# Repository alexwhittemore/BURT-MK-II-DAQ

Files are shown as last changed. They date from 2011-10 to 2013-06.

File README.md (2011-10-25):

BURT Mk-II DAQ
==============

Boston University Rocket Team's Mk-II Data Acquisition and Control System.

Background
----------
The Boston University Rocket Team is currently focused on advancing hybrid rocket motor design and research. The Mk-II is a static (never leaves the ground) test bed for experimentation with various design parameters like chamber and oxidizer injector geometries.

### Sensors
The DAQ side consists of multiple sensors: pressure transducers, load cells, and thermocouples.

There are two pressure transducers, each rated at 500PSI full scale. The Oxidizer Line Transducer measures the pressure on the nitrous oxide feed line right before the injector. This should match the vapor pressure of N2O, roughly 750PSI dependent on temperature. The Combustion Chamber Transducer measures the pressure INSIDE the combustion chamber, directly after the injector. For Mk-II, the design chamber pressure is 500PSI

There are also two load cells. The Thrust Load Cell is an S-Beam, 500lbs full scale load cell. Design thrust is 75lbs. The Oxidizer Tank Cell is a canteliver 50lbs cell. This measures the weight of the Nitrous Oxide tank used to feed the motor, where change in mass of the tank can be used to calculate mass flow rate of oxidizer.

There are three thermocouples. All are K-type. One NPT-threaded, sealed TC measures oxidizer temperature before the injector. One of two silicone surface adhesive TCs measures the oxidizer tank temperature. The other of these measures the combustion chamber casing temperature. A spike in this temperature indicates a fault with the fuel grain casting and a potentially unsafe conditon that could result in a burn-through of the schedule-80 steel casing.

### Boards
All of these are read by four wheatstone bridge digitizer boards (Bridge Digitizer.sch) and three K-type thermocouple digitizer boards (Thermocouple Digitizer.sch). The outputs of these boards are read via SPI by an mbed microcontroller residing on a main board. This main board also holds a zigbee radio which forwards a UART connection to a host computer for off-site (safe distance) live monitoring of the system, as well as a USB plug for a thumb drive to log the live, real-time acquired data. Additionally, a UART is broken out on a set of .1" spaced headers to connect to a sparkfun graphical LCD for on-site monitoring. Finally, two pins are broken out on a DB-9 connector to serve as software serial to a safe distance physical control interface. This could just as easily be run exclusively via zigbee radio.

### Control
The final job of the system is to control the burn itself. This is handled by two pneumatic valves, switched by 24-volt electric solenoids in turn controlled by the mbed via a quad-half H-bridge chip on the main board. These solenoids are either open or spring-shut, and thus only require two outputs of the quad half Bridge. A third output is used to control a nichrome wire-based pyrotechnic ignitor. The fourth half bridge is implemented but unused.

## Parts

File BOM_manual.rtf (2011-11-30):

1uF tantalum filter board cap DigiKey #399-3678-1-ND
USB A sockets DigiKey #GSB311131HR-ND
Tip29 DigiKey #TIP29CFS-ND
1k 25 turn gain trim pots DigiKey #3296w-102LF-ND
filter clock driver Mouser #863-M74VHC1GT126DT1G
Female Break-away Headers DigiKey #929974E-01-36-ND
Male Break-away Headers DigiKey #929834E-01-36-ND
16 Pin IC Socket Sparkfun
Screw Terminals - 2pos 5MM Sparkfun
Xbee headers Sparkfun
DB9 board-mount plugs Sparkfun

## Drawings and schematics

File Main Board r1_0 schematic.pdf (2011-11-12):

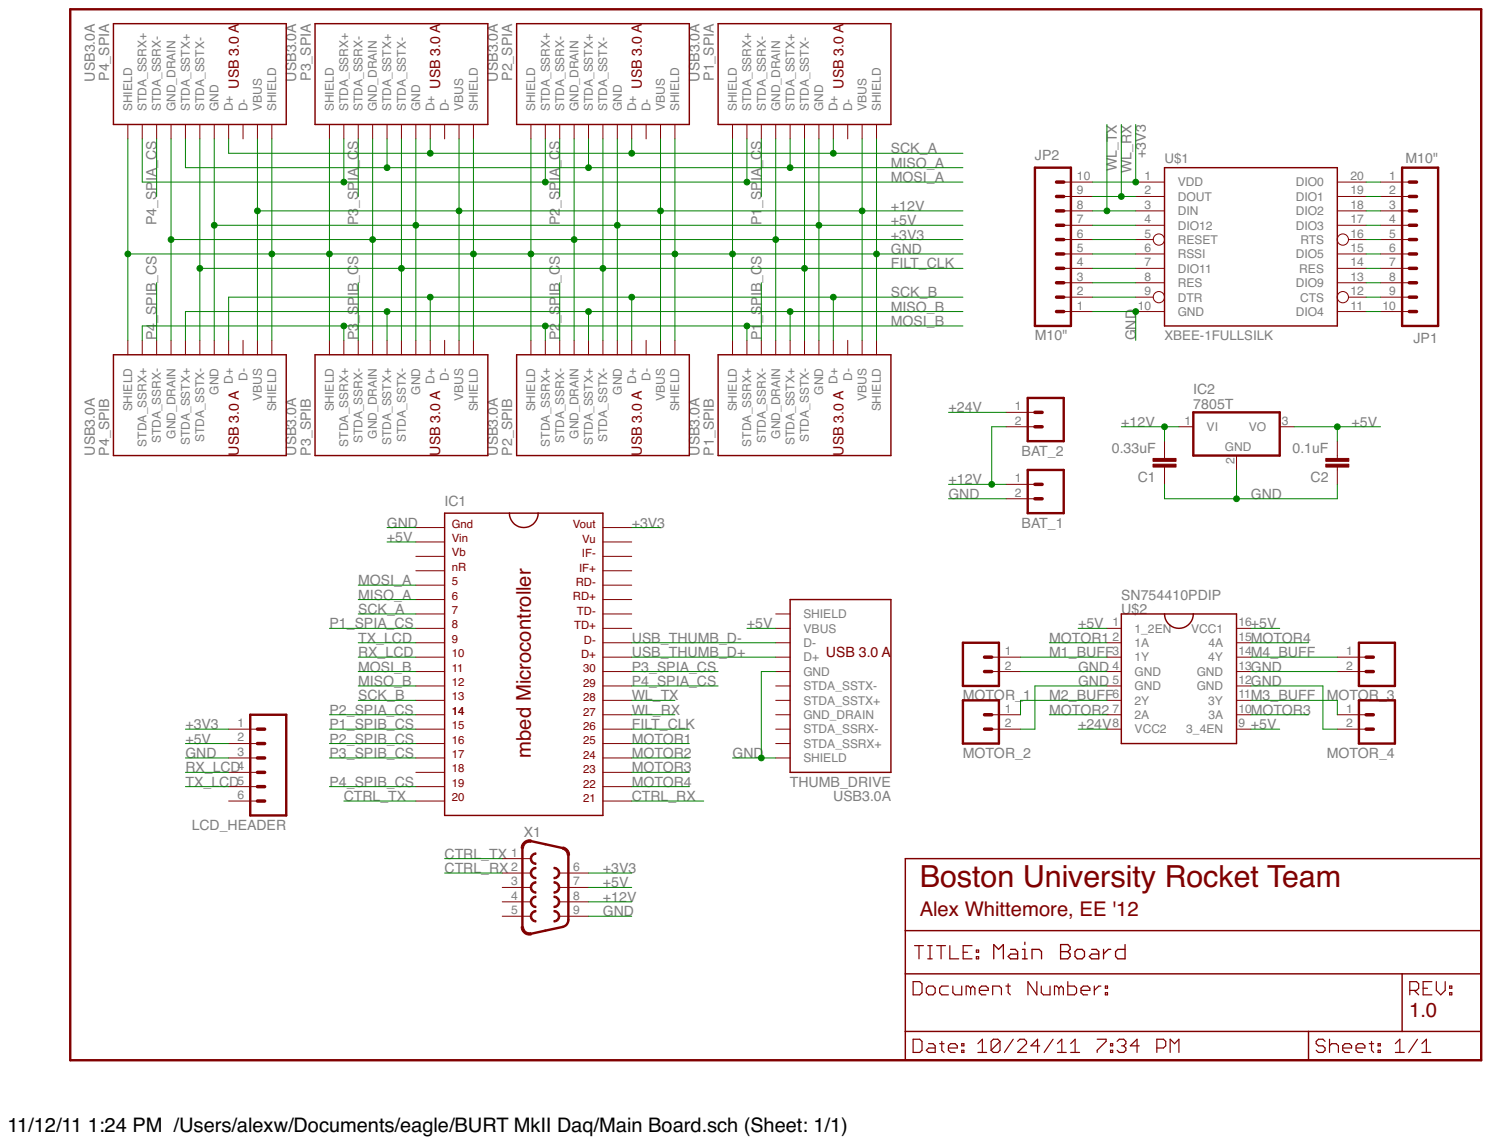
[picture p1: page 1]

Vout Vu

11/12/11 1:24 PM /Users/alexw/Documents/eagle/BURT MkII Daq/Main Board.sch (Sheet: 1/1)

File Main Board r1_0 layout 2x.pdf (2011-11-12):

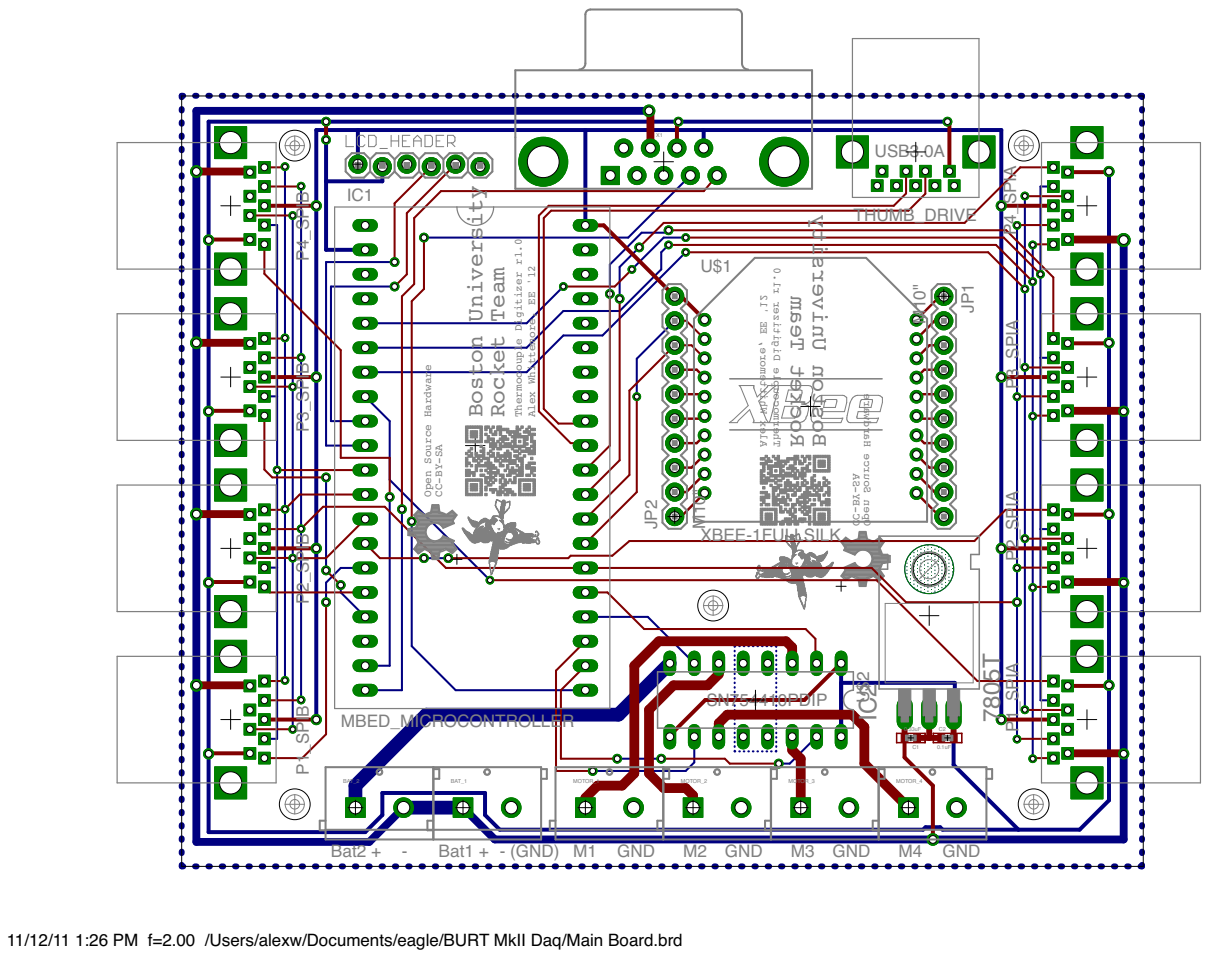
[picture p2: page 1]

11/12/11 1:26 PM f=2.00 /Users/alexw/Documents/eagle/BURT MkII Daq/Main Board.brd

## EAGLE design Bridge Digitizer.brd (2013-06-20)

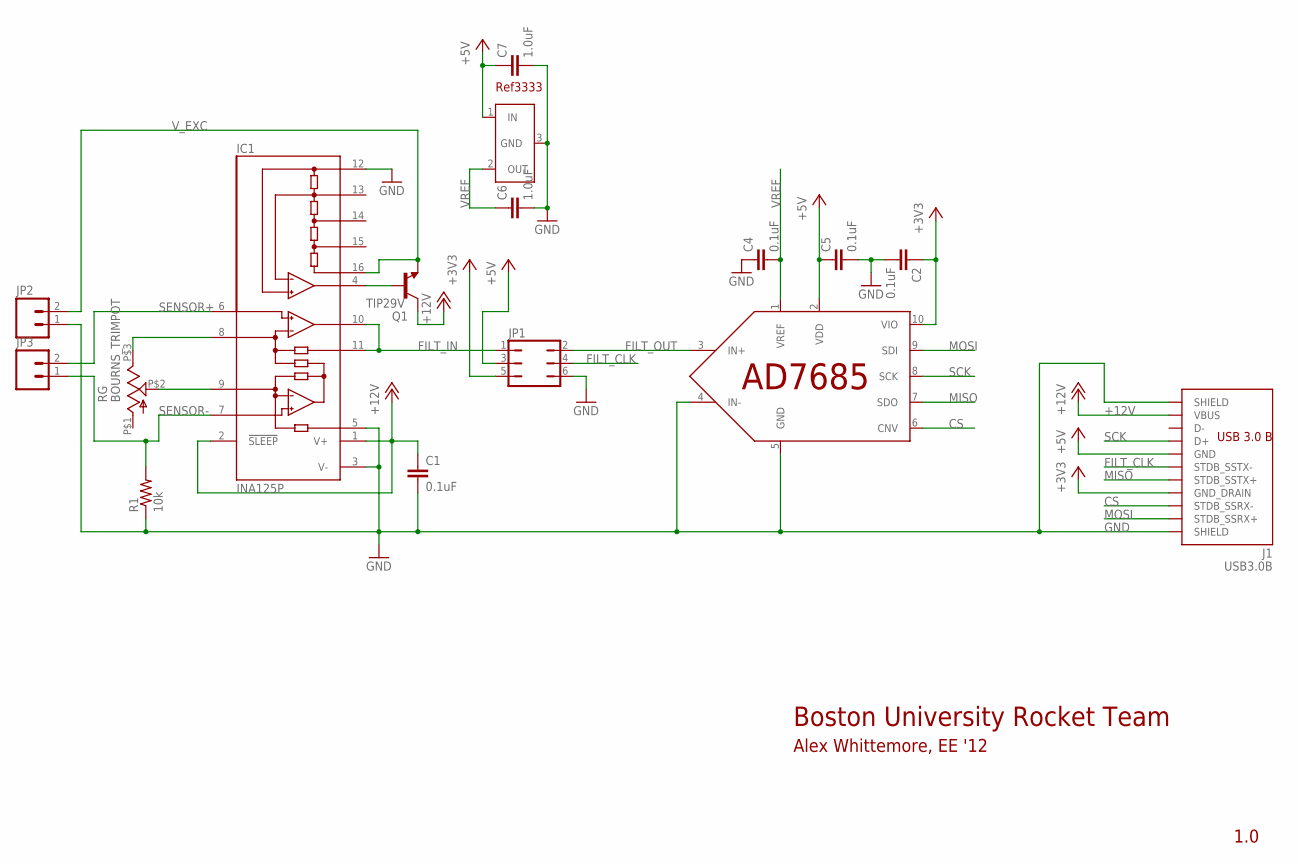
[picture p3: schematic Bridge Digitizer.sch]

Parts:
C1, C2, C4, C5: 0.1uF; 0402-CAP
C6, C7: 1.0uF; 0402-CAP
IC1: INA125P; DIL16
IC3: AD7685; MSOP10
IC4: REF3333; SOT23
J1: USB3.0B; AMPHENOLUSB3.0B
JP1: JP3Q
JP2, JP3: M025MM; SCREWTERMINAL-5MM-2
Q1: TIP29V; TO220V
R1: 10k; 0207/7
RG: BOURNS_TRIMPOT; 3296W

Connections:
+3V3: C2.1, IC3.10 (VIO), J1.7 (GND_DRAIN), JP1.5
+5V: C5.1, C7.1, IC3.2 (VDD), IC4.1 (IN), J1.4 (GND), JP1.3
+12V: C1.1, IC1.1 (V+), IC1.2 (!SLEEP), J1.1 (VBUS), Q1.2 (C)
CS: IC3.6 (CNV), J1.8 (STDB_SSRX-)
FILT_CLK: J1.5 (STDB_SSTX-), JP1.4
FILT_IN: IC1.10 (OUT), IC1.11 (SENSE), JP1.1
FILT_OUT: IC3.3 (IN+), JP1.2
GND: C1.2, C2.2, C4.1, C5.2, C6.2, C7.2, IC1.3 (V-), IC1.5 (REF), IC1.12 (REFCOM), IC3.4 (IN-), IC3.5 (GND), IC4.3 (GND), J1.10@1 (SHIELD), J1.10@2 (SHIELD), JP1.6, JP2.1, R1.1
MISO: IC3.7 (SDO), J1.6 (STDB_SSTX+)
MOSI: IC3.9 (SDI), J1.9 (STDB_SSRX+)
unnamed: IC1.4 (REFOUT), Q1.1 (B)
unnamed: IC1.9 (RG), RG.P$2 (2)
unnamed: IC1.8 (RG), RG.P$3 (3)
SCK: IC3.8 (SCK), J1.3 (D+)
SENSOR+: IC1.6 (+IN), JP3.2
SENSOR-: IC1.7 (-IN), JP3.1, R1.2
VREF: C4.2, C6.1, IC3.1 (VREF), IC4.2 (OUT)
V_EXC: IC1.16 (REF10), JP2.2, Q1.3 (E)

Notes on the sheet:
Boston University Rocket Team
1.0
Alex Whittemore, EE '12

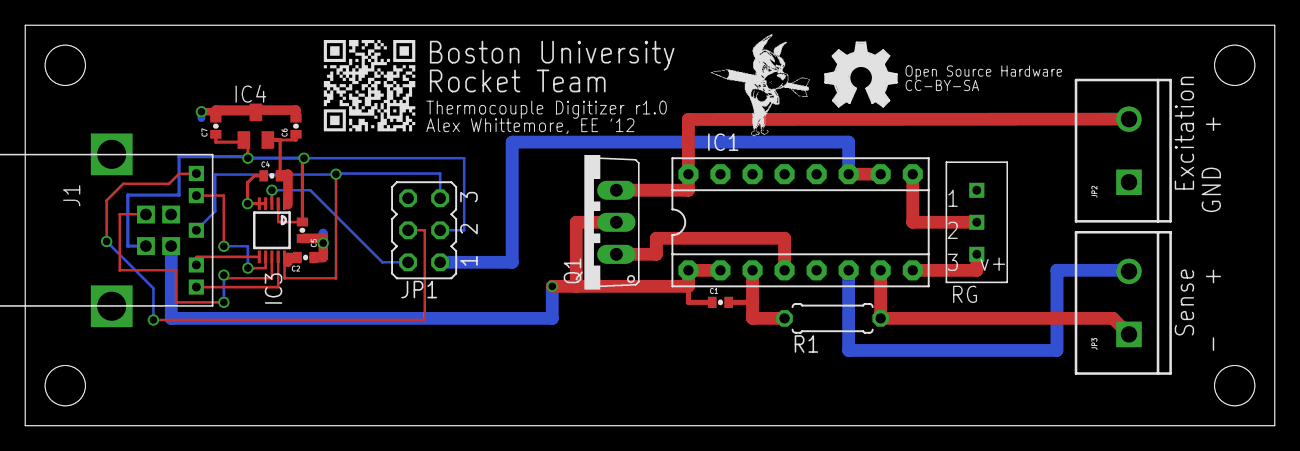
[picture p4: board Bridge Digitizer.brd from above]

Board: 2 copper layers, 99.1 x 31.8 mm, 17 parts (0 on the bottom side), 18 nets.

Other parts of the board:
U$1: OSHW_FILLX200_NOTEXT

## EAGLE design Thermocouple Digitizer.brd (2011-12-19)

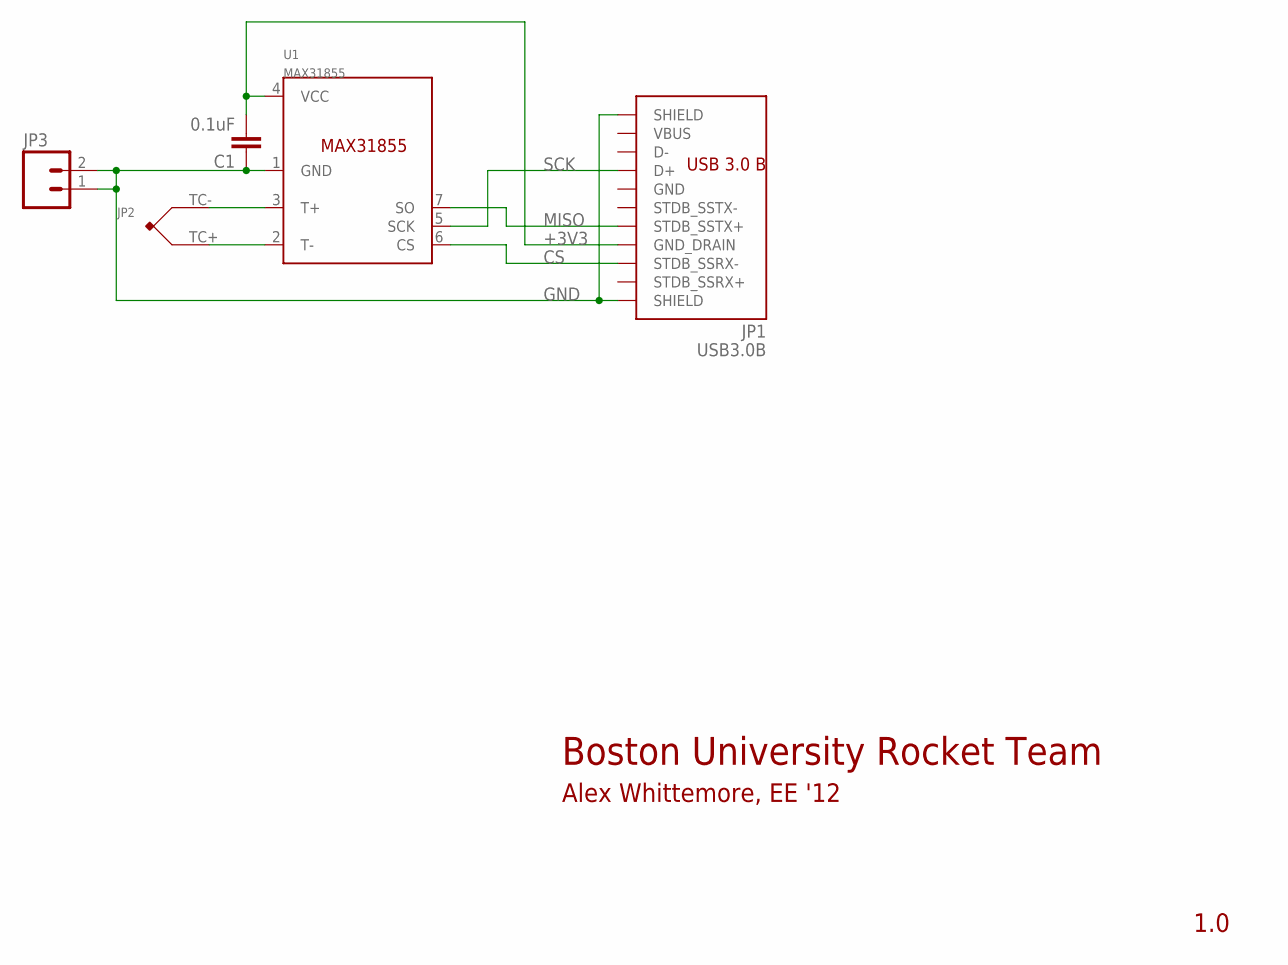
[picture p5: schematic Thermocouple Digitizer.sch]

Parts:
C1: 0.1uF; 0402-CAP
JP1: USB3.0B; AMPHENOLUSB3.0B
JP2: OMEGA_PCC-SMP
JP3: M025MM; SCREWTERMINAL-5MM-2
U1: MAX31855; SOIC8

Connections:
+3V3: C1.2, JP1.7 (GND_DRAIN), U1.4 (VCC)
CS: JP1.8 (STDB_SSRX-), U1.6 (CS)
GND: C1.1, JP1.10@1 (SHIELD), JP1.10@2 (SHIELD), JP3.1, JP3.2, U1.1 (GND)
MISO: JP1.6 (STDB_SSTX+), U1.7 (SO)
unnamed: JP2.TC-, U1.3 (T+)
unnamed: JP2.TC+, U1.2 (T-)
SCK: JP1.3 (D+), U1.5 (SCK)

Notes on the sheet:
Boston University Rocket Team
Alex Whittemore, EE '12
1.0

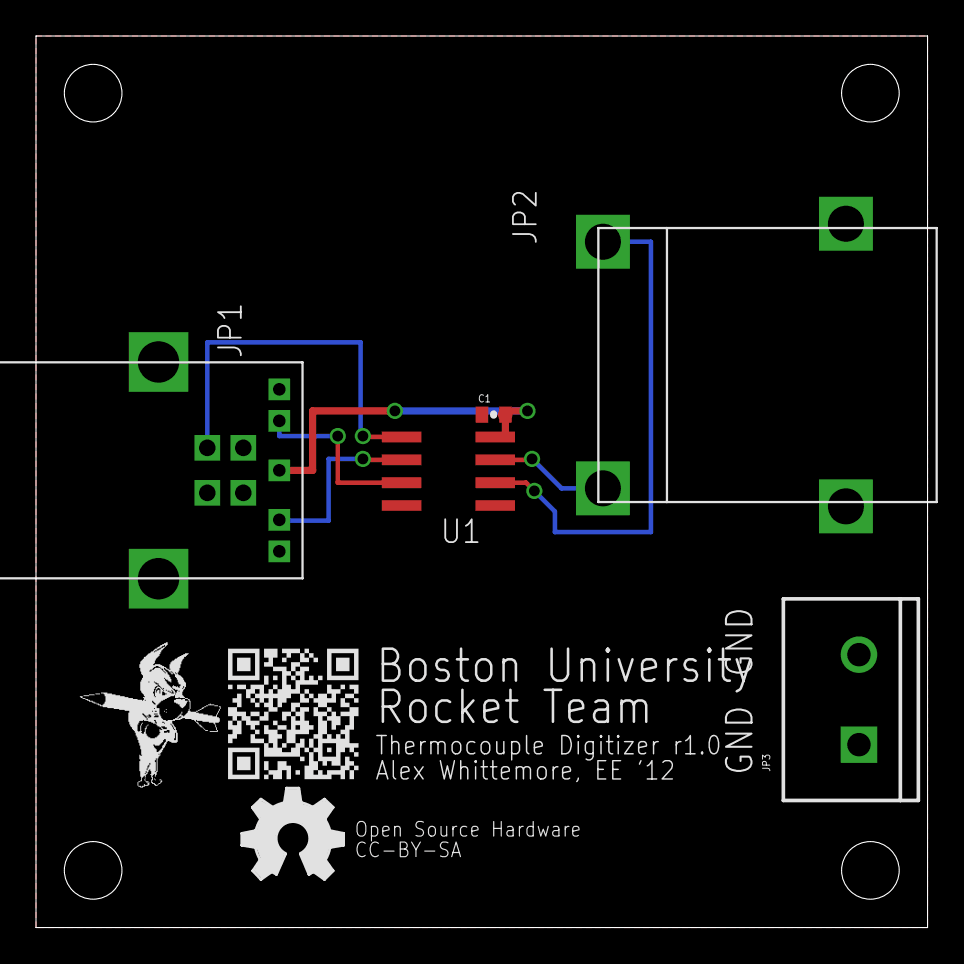
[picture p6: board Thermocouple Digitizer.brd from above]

Board: 2 copper layers, 49.5 x 49.5 mm, 6 parts (0 on the bottom side), 7 nets.

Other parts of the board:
U$1: OSHW_FILLX200_NOTEXT

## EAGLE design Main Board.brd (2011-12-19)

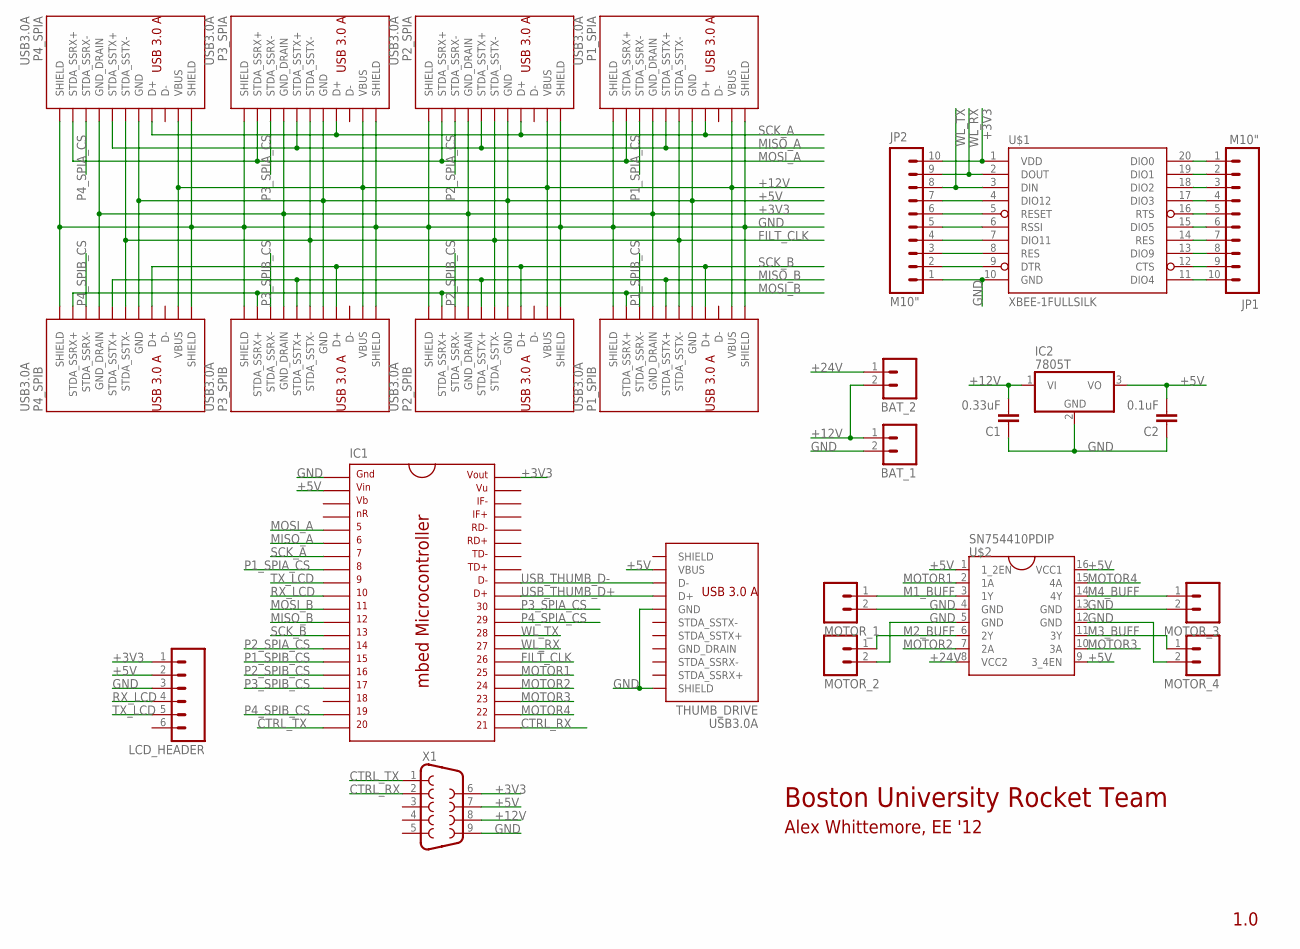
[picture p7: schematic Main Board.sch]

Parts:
BAT_1, BAT_2: M025MM; SCREWTERMINAL-5MM-2
C1: 0.33uF; 0402-CAP
C2: 0.1uF; 0402-CAP
IC1: MBED_MICROCONTROLLER; DIL40_0.9
IC2: 7805T; TO220H
JP1, JP2: M10"; 1X10
LCD_HEADER: M06LOCK; 1X06_LOCK
MOTOR_1, MOTOR_2, MOTOR_3, MOTOR_4: M025MM; SCREWTERMINAL-5MM-2
P1_SPIA, P1_SPIB, P2_SPIA, P2_SPIB, P3_SPIA, P3_SPIB, P4_SPIA, P4_SPIB: USB3.0A; AMPHENOLUSB3.0A
THUMB_DRIVE: USB3.0A; AMPHENOLUSB3.0A
U$1: XBEE-1FULLSILK; XBEE
U$2: SN754410PDIP; DIL16
X1: DB9MALE; DB9_MALE

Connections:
+3V3: IC1.40, JP2.10, LCD_HEADER.1, P1_SPIA.7 (GND_DRAIN), P1_SPIB.7 (GND_DRAIN), P2_SPIA.7 (GND_DRAIN), P2_SPIB.7 (GND_DRAIN), P3_SPIA.7 (GND_DRAIN), P3_SPIB.7 (GND_DRAIN), P4_SPIA.7 (GND_DRAIN), P4_SPIB.7 (GND_DRAIN), U$1.1 (VDD), X1.6
+5V: C2.2, IC1.2, IC2.3 (VO), LCD_HEADER.2, P1_SPIA.4 (GND), P1_SPIB.4 (GND), P2_SPIA.4 (GND), P2_SPIB.4 (GND), P3_SPIA.4 (GND), P3_SPIB.4 (GND), P4_SPIA.4 (GND), P4_SPIB.4 (GND), THUMB_DRIVE.1 (VBUS), U$2.1 (1_2EN), U$2.9 (3_4EN), U$2.16 (VCC1), X1.7
+12V: BAT_1.1, BAT_2.2, C1.2, IC2.1 (VI), P1_SPIA.1 (VBUS), P1_SPIB.1 (VBUS), P2_SPIA.1 (VBUS), P2_SPIB.1 (VBUS), P3_SPIA.1 (VBUS), P3_SPIB.1 (VBUS), P4_SPIA.1 (VBUS), P4_SPIB.1 (VBUS), X1.8
+24V: BAT_2.1, U$2.8 (VCC2)
CTRL_RX: IC1.21, X1.2
CTRL_TX: IC1.20, X1.1
FILT_CLK: IC1.26, P1_SPIA.8 (STDA_SSTX-), P1_SPIB.8 (STDA_SSTX-), P2_SPIA.8 (STDA_SSTX-), P2_SPIB.8 (STDA_SSTX-), P3_SPIA.8 (STDA_SSTX-), P3_SPIB.8 (STDA_SSTX-), P4_SPIA.8 (STDA_SSTX-), P4_SPIB.8 (STDA_SSTX-)
GND: BAT_1.2, C1.1, C2.1, IC1.1, IC2.2 (GND), JP2.1, LCD_HEADER.3, MOTOR_1.2, MOTOR_2.2, MOTOR_3.2, MOTOR_4.2, P1_SPIA.10@1 (SHIELD), P1_SPIA.10@2 (SHIELD), P1_SPIB.10@1 (SHIELD), P1_SPIB.10@2 (SHIELD), P2_SPIA.10@1 (SHIELD), P2_SPIA.10@2 (SHIELD), P2_SPIB.10@1 (SHIELD), P2_SPIB.10@2 (SHIELD), P3_SPIA.10@1 (SHIELD), P3_SPIA.10@2 (SHIELD), P3_SPIB.10@1 (SHIELD), P3_SPIB.10@2 (SHIELD), P4_SPIA.10@1 (SHIELD), P4_SPIA.10@2 (SHIELD), P4_SPIB.10@1 (SHIELD), P4_SPIB.10@2 (SHIELD), THUMB_DRIVE.4 (GND), THUMB_DRIVE.10@2 (SHIELD), U$1.10 (GND), U$2.4 (GND), U$2.5 (GND), U$2.12 (GND), U$2.13 (GND), X1.9
M1_BUFF: MOTOR_1.1, U$2.3 (1Y)
M2_BUFF: MOTOR_2.1, U$2.6 (2Y)
M3_BUFF: MOTOR_4.1, U$2.11 (3Y)
M4_BUFF: MOTOR_3.1, U$2.14 (4Y)
MISO_A: IC1.6, P1_SPIA.9 (STDA_SSTX+), P2_SPIA.9 (STDA_SSTX+), P3_SPIA.9 (STDA_SSTX+), P4_SPIA.9 (STDA_SSTX+)
MISO_B: IC1.12, P1_SPIB.9 (STDA_SSTX+), P2_SPIB.9 (STDA_SSTX+), P3_SPIB.9 (STDA_SSTX+), P4_SPIB.9 (STDA_SSTX+)
MOSI_A: IC1.5, P1_SPIA.6 (STDA_SSRX+), P2_SPIA.6 (STDA_SSRX+), P3_SPIA.6 (STDA_SSRX+), P4_SPIA.6 (STDA_SSRX+)
MOSI_B: IC1.11, P1_SPIB.6 (STDA_SSRX+), P2_SPIB.6 (STDA_SSRX+), P3_SPIB.6 (STDA_SSRX+), P4_SPIB.6 (STDA_SSRX+)
MOTOR1: IC1.25, U$2.2 (1A)
MOTOR2: IC1.24, U$2.7 (2A)
MOTOR3: IC1.23, U$2.10 (3A)
MOTOR4: IC1.22, U$2.15 (4A)
unnamed: JP2.7, U$1.4 (DIO12)
unnamed: JP2.6, U$1.5 (RESET)
unnamed: JP2.5, U$1.6 (RSSI)
unnamed: JP2.4, U$1.7 (DIO11)
unnamed: JP2.3, U$1.8 (RES)
unnamed: JP2.2, U$1.9 (DTR)
unnamed: JP1.1, U$1.20 (DIO0)
unnamed: JP1.2, U$1.19 (DIO1)
unnamed: JP1.3, U$1.18 (DIO2)
unnamed: JP1.4, U$1.17 (DIO3)
unnamed: JP1.5, U$1.16 (RTS)
unnamed: JP1.6, U$1.15 (DIO5)
unnamed: JP1.7, U$1.14 (RES)
unnamed: JP1.8, U$1.13 (DIO9)
unnamed: JP1.9, U$1.12 (CTS)
unnamed: JP1.10, U$1.11 (DIO4)
P1_SPIA_CS: IC1.8, P1_SPIA.5 (STDA_SSRX-)
P1_SPIB_CS: IC1.15, P1_SPIB.5 (STDA_SSRX-)
P2_SPIA_CS: IC1.14, P2_SPIA.5 (STDA_SSRX-)
P2_SPIB_CS: IC1.16, P2_SPIB.5 (STDA_SSRX-)
P3_SPIA_CS: IC1.30, P3_SPIA.5 (STDA_SSRX-)
P3_SPIB_CS: IC1.17, P3_SPIB.5 (STDA_SSRX-)
P4_SPIA_CS: IC1.29, P4_SPIA.5 (STDA_SSRX-)
P4_SPIB_CS: IC1.19, P4_SPIB.5 (STDA_SSRX-)
RX_LCD: IC1.10, LCD_HEADER.4
SCK_A: IC1.7, P1_SPIA.3 (D+), P2_SPIA.3 (D+), P3_SPIA.3 (D+), P4_SPIA.3 (D+)
SCK_B: IC1.13, P1_SPIB.3 (D+), P2_SPIB.3 (D+), P3_SPIB.3 (D+), P4_SPIB.3 (D+)
TX_LCD: IC1.9, LCD_HEADER.5
USB_THUMB_D+: IC1.31, THUMB_DRIVE.3 (D+)
USB_THUMB_D-: IC1.32, THUMB_DRIVE.2 (D-)
WL_RX: IC1.27, JP2.9, U$1.2 (DOUT)
WL_TX: IC1.28, JP2.8, U$1.3 (DIN)

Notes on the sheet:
Boston University Rocket Team
Alex Whittemore, EE '12
1.0

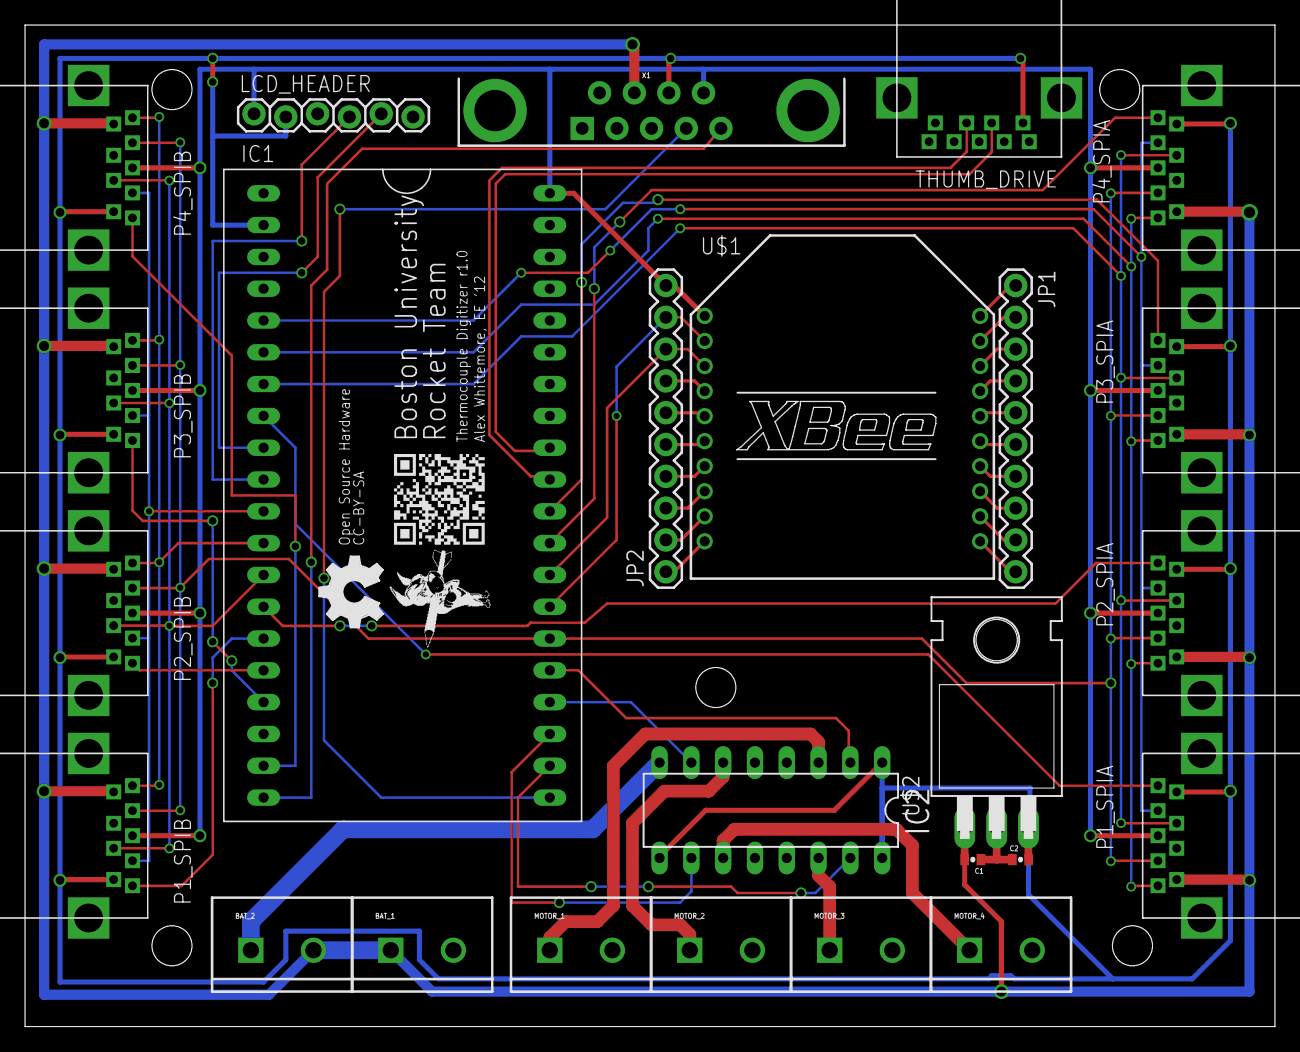
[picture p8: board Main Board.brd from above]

Board: 2 copper layers, 99.8 x 80.0 mm, 27 parts (1 on the bottom side), 52 nets.

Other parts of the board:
U$3, U$4: OSHW_FILLX200_NOTEXT

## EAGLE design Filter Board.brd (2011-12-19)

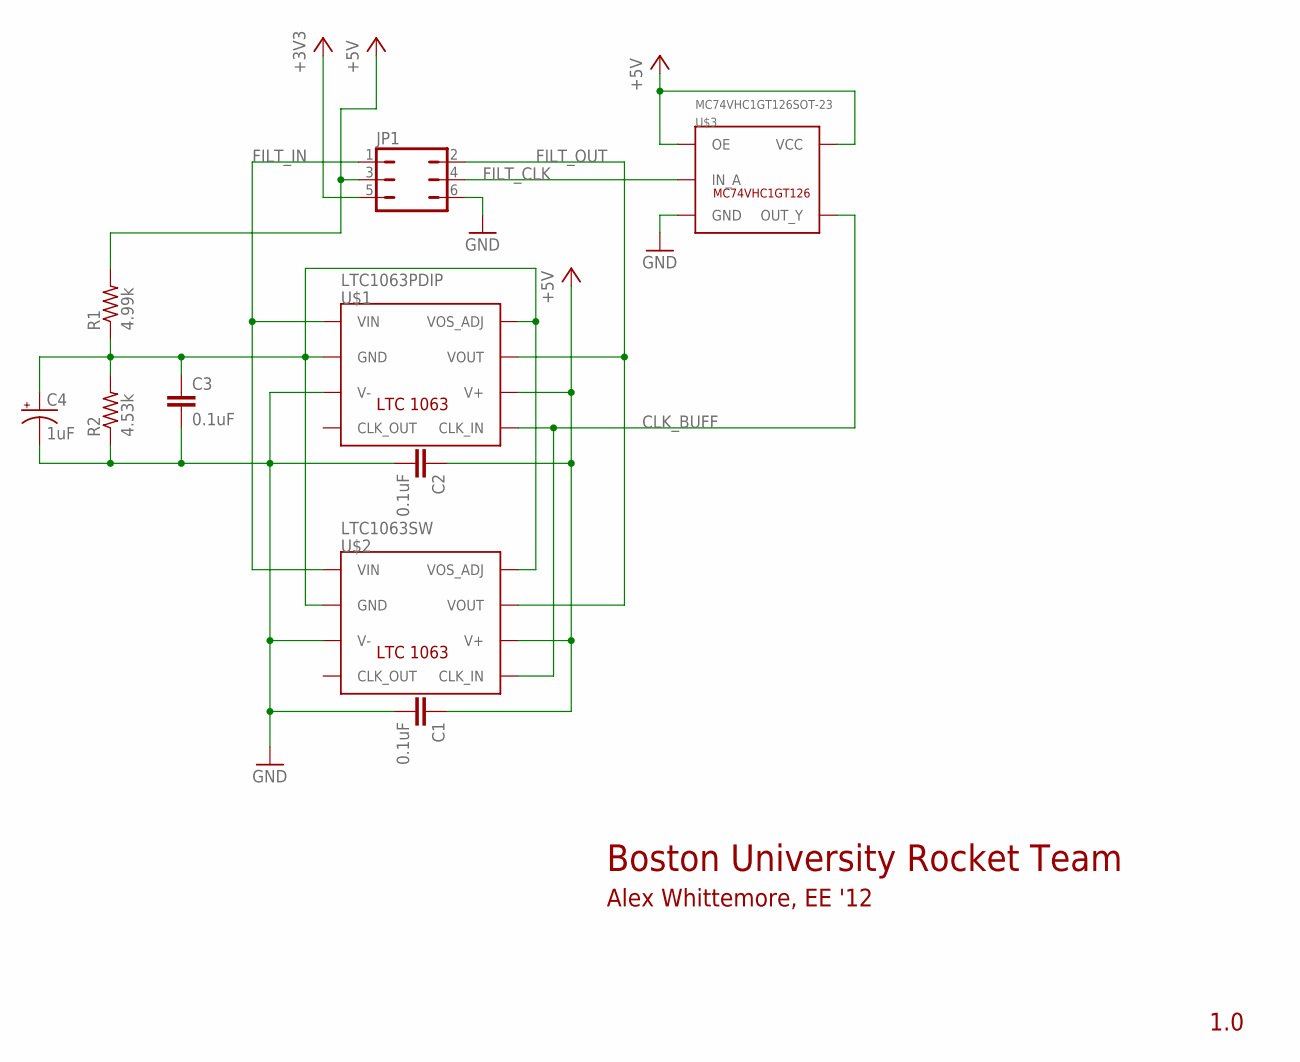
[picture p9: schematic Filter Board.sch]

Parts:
C1, C2, C3: 0.1uF; 0402-CAP
C4: 1uF; EIA3216
JP1: JP3Q
R1: 4.99k; 0207/7
R2: 4.53k; 0207/7
U$1: LTC1063PDIP; SOCKED-08
U$2: LTC1063SW; SOP16
U$3: MC74VHC1GT126SOT-23; SOT23-5L

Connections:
+3V3: JP1.5
+5V: C1.1, C2.1, JP1.3, R1.2, U$1.6 (V+), U$2.12 (V+), U$3.1 (OE), U$3.5 (VCC)
CLK_BUFF: U$1.5 (CLK_IN), U$2.9 (CLK_IN), U$3.4 (OUT_Y)
FILT_CLK: JP1.4, U$3.2 (IN_A)
FILT_IN: JP1.1, U$1.1 (VIN), U$2.2 (VIN)
FILT_OUT: JP1.2, U$1.7 (VOUT), U$2.14 (VOUT)
GND: C1.2, C2.2, C3.2, C4.C (-), JP1.6, R2.1, U$1.3 (V-), U$2.5 (V-), U$3.3 (GND)
unnamed: C3.1, C4.A (+), R1.1, R2.2, U$1.2 (GND), U$1.8 (VOS_ADJ), U$2.3 (GND), U$2.16 (VOS_ADJ)

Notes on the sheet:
Boston University Rocket Team
1.0
Alex Whittemore, EE '12

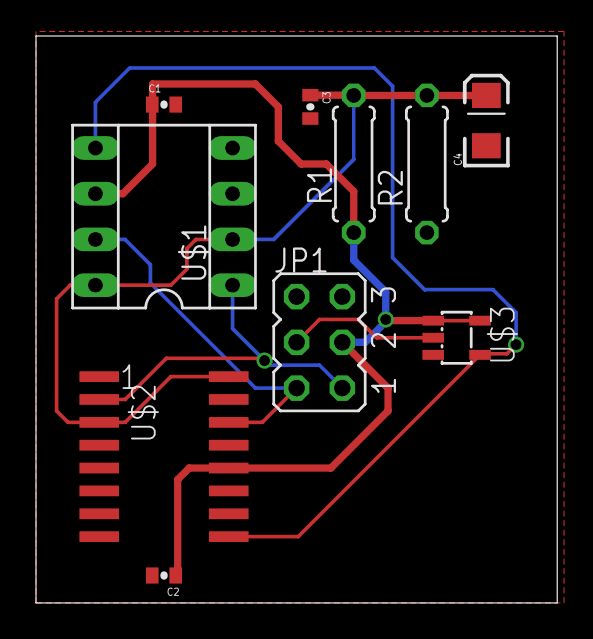
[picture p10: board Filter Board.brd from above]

Board: 2 copper layers, 29.0 x 31.5 mm, 10 parts (0 on the bottom side), 7 nets.

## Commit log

2011-10-25 Initial commit of four boards, all rev1.0.
    [Bridge Digitizer.brd, Bridge Digitizer.sch, Filter Board.brd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]
2011-10-25 Added final taped-out rev1.0 gerber files for all boards.
    [Bridge Digitizer.GBL, Bridge Digitizer.GBO, Bridge Digitizer.GBS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]
2011-11-12 Added r1.0 main board PDFs for reference.
2011-12-19 Converted to new Eagle V6 XML format
    [Bridge Digitizer.brd, Bridge Digitizer.sch, Filter Board.brd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]
2013-06-20 ignore eagle.epf
    [Bridge Digitizer.brd]

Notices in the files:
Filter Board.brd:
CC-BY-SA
